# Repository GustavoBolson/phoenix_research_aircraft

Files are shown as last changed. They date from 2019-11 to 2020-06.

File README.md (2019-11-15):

# phoenix_research_aircraft
In an effort to apply my knowledge gained in engineering undergraduate up until this point in a real world, systems engineering based, all-phases design, I will be designing a series of small uncrewed research aircraft to test both aircraft design technics and electronic systems ranging from control to scientific payload that could benefit from having a low-cost, variable acceleration environment. This is supposed to be an easy access venue for future researchers and students who want to replicate my findings or just anyone interested in small planes in general. Fell free to use it on your own project just citing my name and the version that you used.

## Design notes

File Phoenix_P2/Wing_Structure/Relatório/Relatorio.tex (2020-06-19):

\documentclass[a4paper]{article}
\usepackage{fullpage}
\usepackage[utf8]{inputenc}
\usepackage{mathtools}
\usepackage[defaultsans]{comfortaa}
\usepackage[T1]{fontenc}
\usepackage{float}
\usepackage{hyperref}
\usepackage{multicol}
\usepackage{wrapfig}
\usepackage{subcaption}

\title{\Large{\textbf{Relatório Final: Análise de Longarina em Estrutura de Asa para o Avião de Pesquisa Phoenix P2}}}
\author{Gustavo Mancuso Bolson}

\begin{document}

\maketitle

\section{Introdução}

Este relatório é o seguinte da \textit{Proposta de Projeto} após as análises e decisões principais da estrutura das asas do projeto Phoenix P2, o qual \textit{in memoriae} é parte integrante de um esforço multidisciplinar de capacitar e desenvolver conhecimentos que permitam uma maior experiência na área de atuação aeroespacial durante a graduação, através do design, construção, realização de ensaios e voos-teste de um avião não-tripulado de características facilmente modificáveis.

Foi realizada uma série de simulações com dois métodos principais: utilizando uma simulação de barra como o estudado na disciplina com esforços mais precisos e um com diferenças finitas que permite maior controle sobre as características da barra que tem a vantagem de oferecer valores confiáveis de limites de escoamento dos materiais testados mas exige algumas simplificações no cálculo dos esforços. Desta forma podemos ter uma discussão informada sobre qual a escolha mais adequada de material e melhoras para o design proposto inicialmente dentro das escalas fornecidas pelos requisitos, que também são avaliados por conformidade neste relatório.

\section{Determinação de Esforços Aerodinâmicos}

Para determinar os esforços aerodinâmicos atuantes nas asas durante operação que não excede os limites mínimos do envelope de voo esperado, uma série de condições para a carga podem ser modeladas: 

A primeira e mais relevante é que a pressão em toda a superfície da asa é contínua e suavemente variável, o que elimina a validade da análise para uma condição de estol com fluxo altamente turbilhonar e caótico. A decisão é justificada pelas cargas envolvidas serem menores do que as esperadas pela própria natureza deste estado de operação, que envolve uma combinação de ângulo de ataque $\alpha$ elevado combinado com uma baixa velocidade verdadeira do ar. Em conjunto a isso e para evitar prolongações burocráticas acordo com as regras de operação de aeromodelos da Agência Nacional de Aviação Civil (ANAC), a variação de densidade do ar em função à altura máxima de 400 pés AGL \cite{anacdrones} não será considerável o suficiente para afetar a análise, que foi feita utilizando uma temperatura aproximada de 20°C a nível do mar.

A segunda é de que as forças que atuam em cada contato com as nervuras mantém-se constantes com relação às coordenadas locais independentemente de deflexão da longarina. Esta condição é válida pois o perfil de pressão local em um corte a uma distância fixa do engaste da asa é determinado apenas pela forma do aerofólio, seu ângulo de ataque $\alpha$ e o número de Reynolds $R_e$ do fluxo. De acordo com a área planiforme retangular das asas, a razão entre envergadura e comprimento de corda de 10, e a desconsideração dos efeitos aerodinâmicos do engaste de ajuste e corpo da aeronave, podemos utilizar a seguinte equação para aproximar a um coeficiente de distribuição de pressão $\Gamma(y)$ da proporção de distância do engaste x. os valores de $a$ e $k$ são dependentes da razão entre corda e envergadura da asa. Se tomamos o valor de $k=1$ (indicando que os valores de y são em semi-envergadura percorrida normalizada), podemos modelar através de um \textit{fit} \cite{WPIpaper} e então determinar o valor de $a\approx 7.6$.

\vspace{0.5cm}

\begin{equation}
    \Gamma(y) = 1-\left(e^{-a\left(y+k\right)}+e^{a\left(y-k\right)}\right)
\end{equation}

\vspace{0.5cm}

Finalmente, para calcular o perfil de pressões em uma seção de aerofólio, foi utilizado um software de simulação/banco de dados XFOIL \cite{xfoil}. Foram escolhidos 3 estados segundo o envelope de voo mínimo, os quais são apresentados a seguir com suas condições de contorno e os resultados de distribuições de pressão que são condensados em forças pontuais para modelagem dos esforços na longarina. Os estados são escolhidos segundo os diagramas polares do aerofólio escolhido (NACA 23015) nos regimes esperados \cite{aftools}.

\begin{figure}[H]
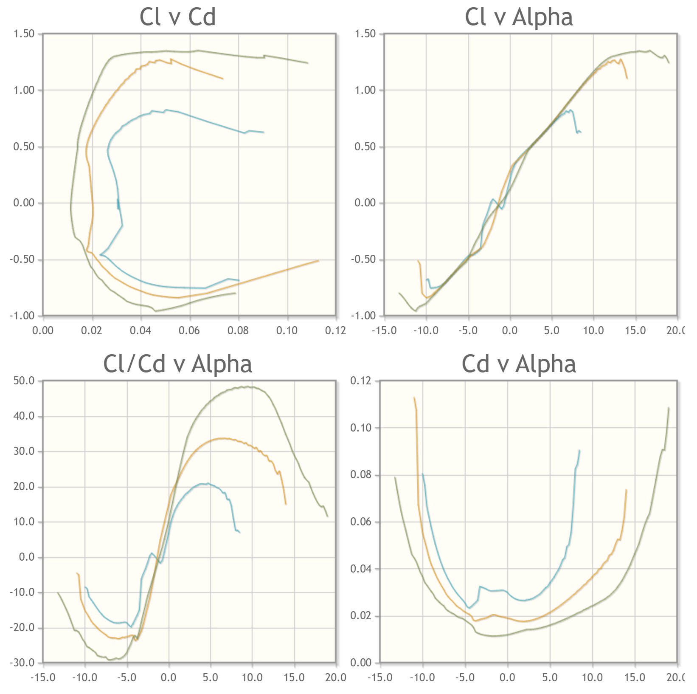
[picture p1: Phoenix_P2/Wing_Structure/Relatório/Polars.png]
    
\end{figure}

A seguir apresentamos 4 estados de operação esperados do aerofólio, incluindo em uma velocidade média esperada para voos iniciais e pré-pousos e outras 3 nas velocidades máximas esperadas variando apenas o ângulo de ataque. Como o terceiro estado (análogo a uma curva coordenada com a maior aceleração centrípeta à maior velocidade esperada) apresenta a maior carga à qual as asas estarão submetidas, esta será a considerada para a análise de esforços. É importante lembrar que qualquer ângulo maior do que 15° a um $R_e=2\times10^5$ resulta em condição de estol, o que reduz a carga na asas.

\begin{figure}[H]
    \begin{subfigure}[b]{0.48\textwidth}
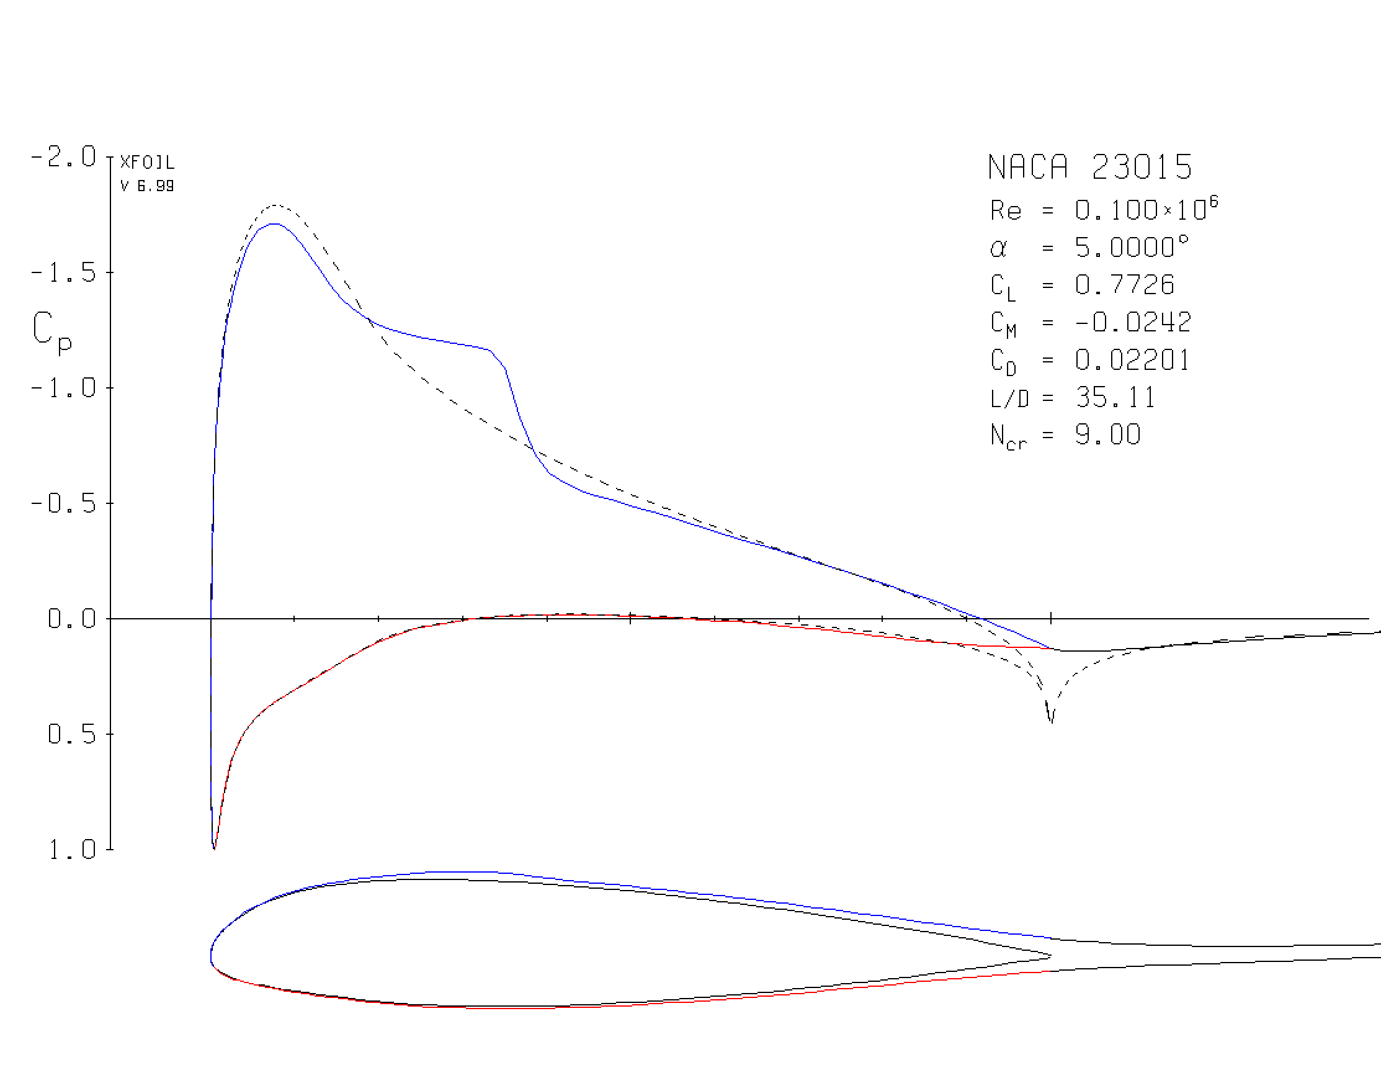
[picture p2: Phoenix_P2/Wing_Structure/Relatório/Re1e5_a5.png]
      
      \caption*{Operação Normal: $\alpha$ = 5° a 8m/s}
    \end{subfigure}
    %
    \begin{subfigure}[b]{0.48\textwidth}
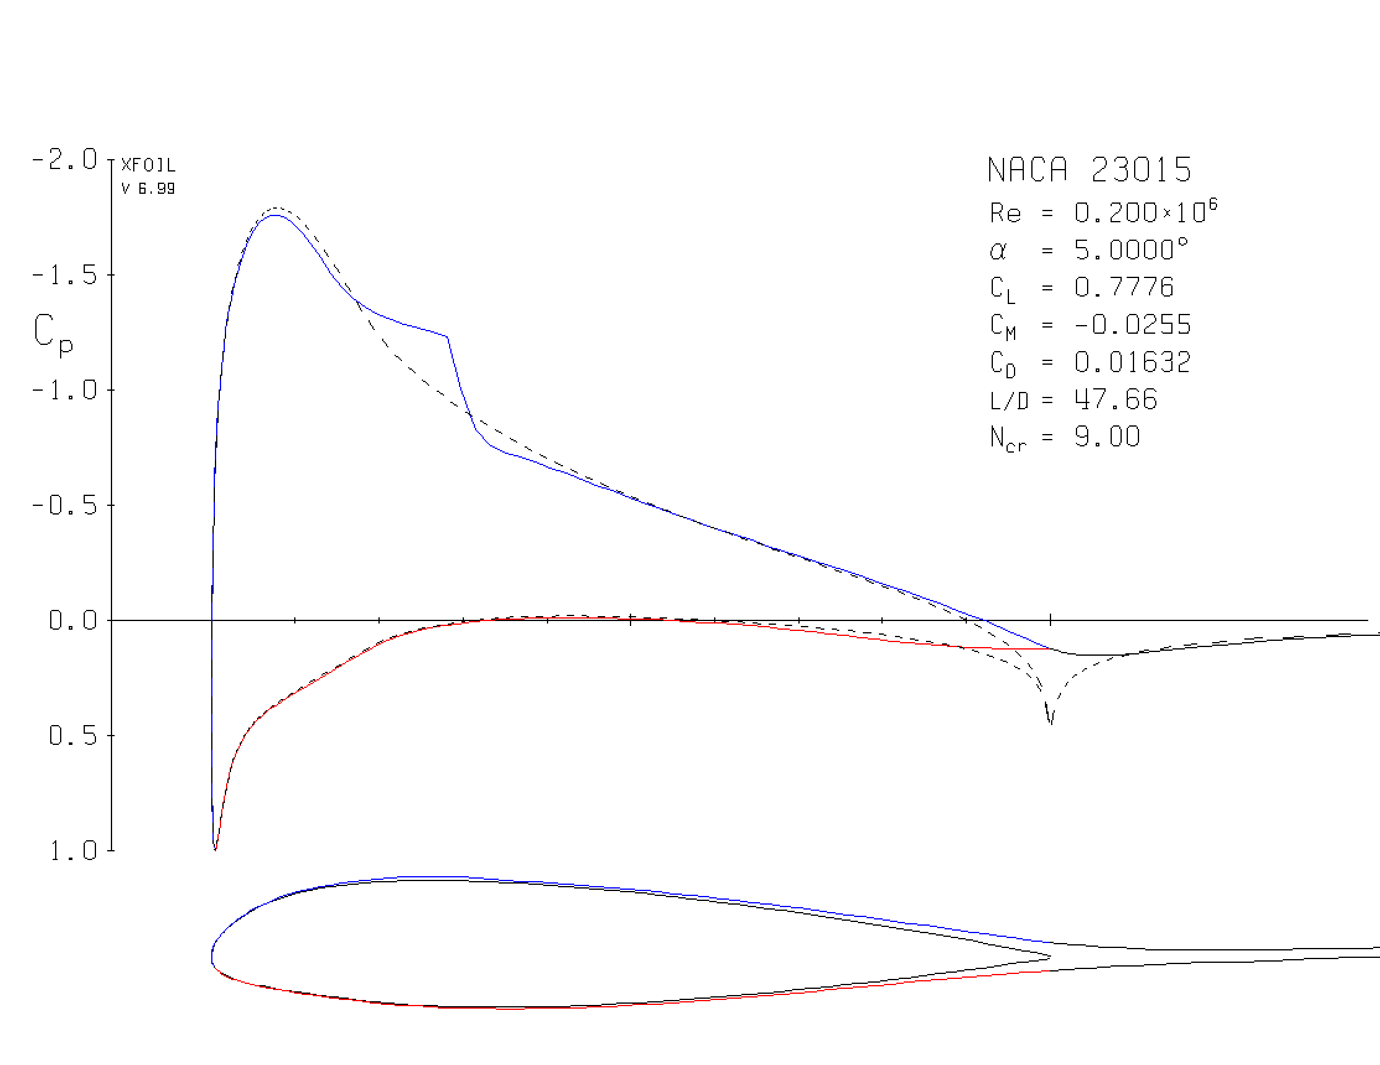
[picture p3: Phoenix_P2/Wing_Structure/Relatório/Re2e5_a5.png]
      
      \caption*{Max. Velocidade: $\alpha$ = 5° a 15m/s}
    \end{subfigure}
\end{figure}

\begin{figure}[H]
    \begin{subfigure}[b]{0.48\textwidth}
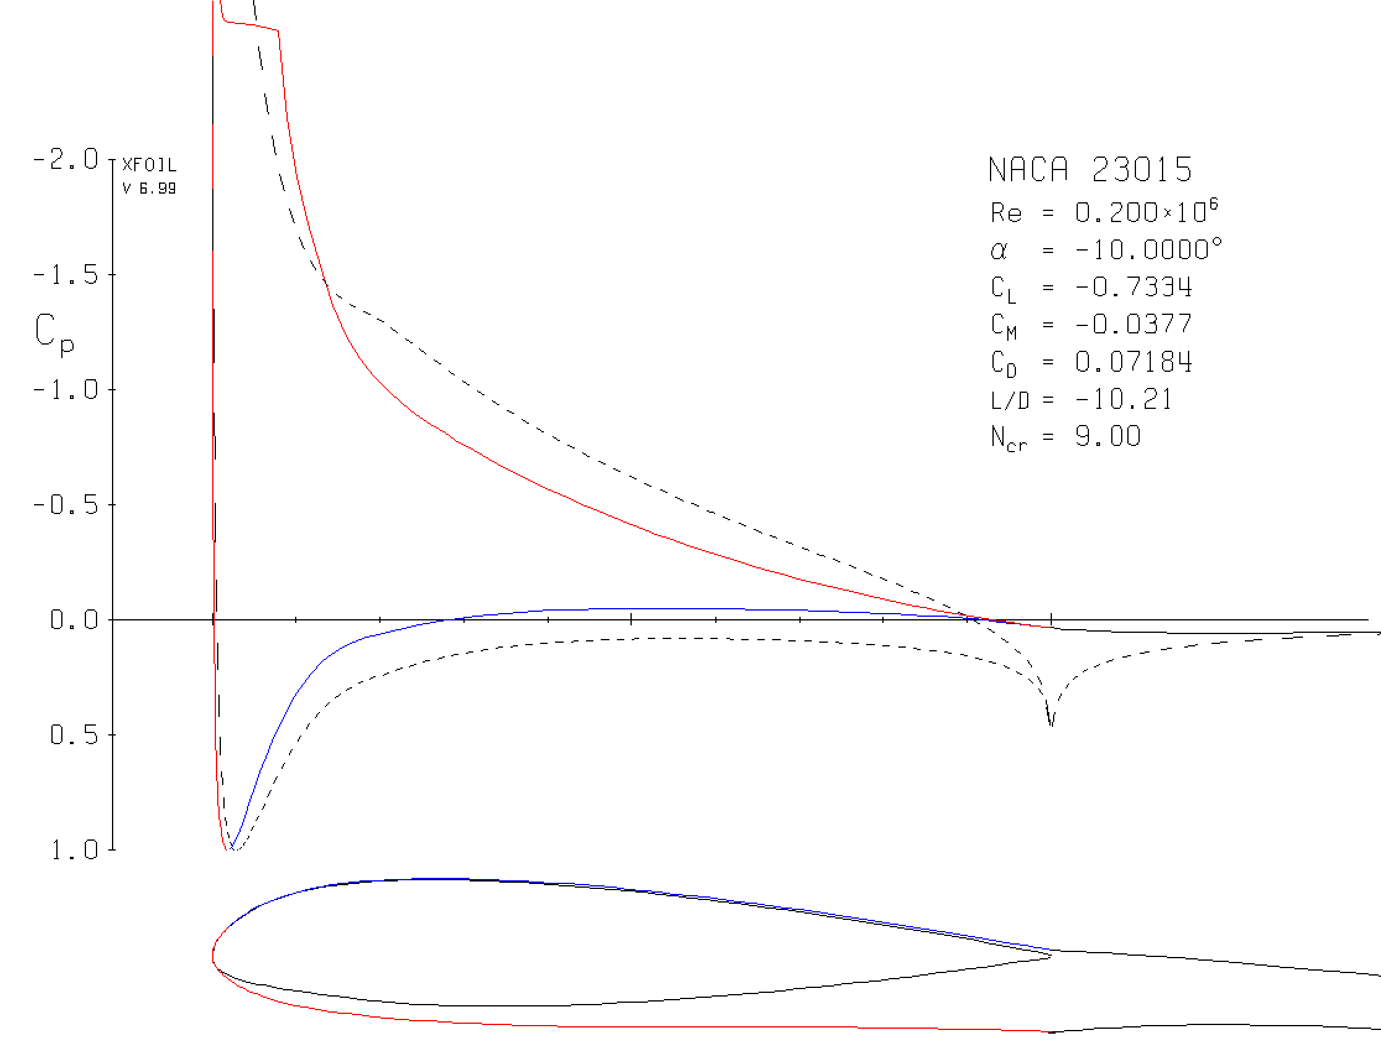
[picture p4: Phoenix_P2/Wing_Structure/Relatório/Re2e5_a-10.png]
      
      \caption*{Max. Velocidade: $\alpha$ = -10° a 15m/s}
    \end{subfigure}
    %
    \begin{subfigure}[b]{0.48\textwidth}
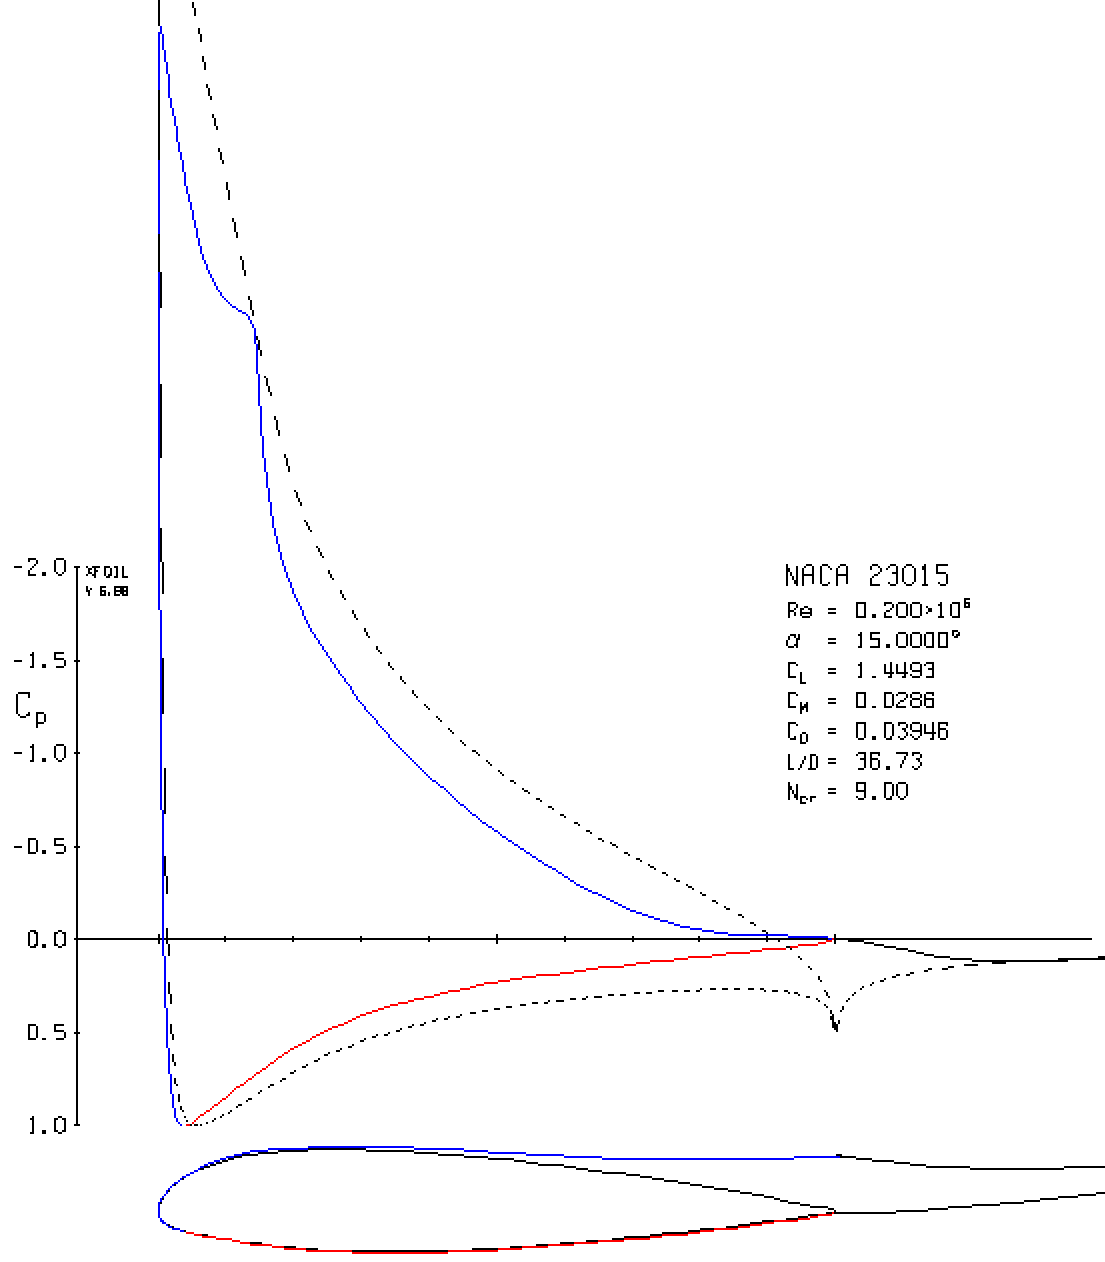
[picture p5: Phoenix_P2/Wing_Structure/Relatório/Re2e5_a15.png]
      
      \caption*{Max. Velocidade: $\alpha$ = 15° a 15m/s}
    \end{subfigure}
\end{figure}

Por fim, podemos tomar os coeficientes adquiridos para calcular quais são as forças de sustentação e arrasto segundo as equações (2) e (3) respectivamente. Os pontos de aplicação da força $L$ e, por consequência, torques envolvidos em cada seção de área é calculada por um \textit{fit} de spline dos diagramas acima, e o perfil é modelado linearmente em coeficiente de $\Gamma(y)$. As equações consideram o centro de coordenadas como sendo a linha de ataque do aerofólio. As medidas são considerando envergadura e corda normalizadas para 1, e são aplicadas para cada nervura. Os termos adicionais são derivados da teoria apresentada por Anderson (2017) \cite{anderson}. Todos as formulas utilizam unidades do sistema internacional.

\vspace{0.5cm}

\begin{minipage}{.47\linewidth}
    \begin{equation}
        L_n = C_L \frac{1}{2} \rho V^2 l \int_{y_{n-1}}^{y_{n+1}} \frac{\Gamma(y)}{2} dy
    \end{equation}
    \begin{equation}
        D_n = C_D \frac{1}{2} \rho V^2 l \int_{y_{n-1}}^{y_{n+1}} \frac{\Gamma(y)}{2} dy + D_0
    \end{equation}
\end{minipage}
\begin{minipage}{.47\linewidth}
    \begin{equation}
        M_x = L (y_L) + C_L \frac{1}{2} \rho V^2 l (1 - \int_{y_{n-1}}^{y_{n+1}} \frac{\Gamma(y)}{2} dy) = 0
    \end{equation}
    \begin{equation}
        M_y = L (x_L - 0.3)
    \end{equation}
    \begin{equation}
        M_z = 0
    \end{equation}
\end{minipage}

\vspace{0.5cm}

\section{Análise de Esforços na Longarina}

Para a execução dos cálculos, foi utilizado a ferramenta de simulação estática do SolidWorks com 10 segmentos como os especificados na \textit{Proposta de Projeto}. Para motivo desta primeira análise, a geometria da seção reta pode ser desconsiderada quando tratamos dos esforços. Em cada junção da barra foi aplicado um par de forças linearmente independentes e um momento torsor, que estão representados na tabela abaixo:

\begin{table}[H]
    \begin{tabular}{llllllllllll}
    y{[}$m${]}   & 0                          & 0.1                         & 0.2                         & 0.3                         & 0.4                         & 0.5                         & 0.6                         & 0.7                         & 0.8                         & 0.9                        & 1                          \\ \cline{2-12} 
    \multicolumn{1}{l|}{$L$} & \multicolumn{1}{l|}{9.804} & \multicolumn{1}{l|}{19.602} & \multicolumn{1}{l|}{19.579} & \multicolumn{1}{l|}{19.524} & \multicolumn{1}{l|}{19.404} & \multicolumn{1}{l|}{19.147} & \multicolumn{1}{l|}{18.598} & \multicolumn{1}{l|}{17.423} & \multicolumn{1}{l|}{14.911} & \multicolumn{1}{l|}{9.540} & \multicolumn{1}{l|}{2.940} \\ \cline{2-12} 
    \multicolumn{1}{l|}{$D$}     & \multicolumn{1}{l|}{1.482} & \multicolumn{1}{l|}{1.481}  & \multicolumn{1}{l|}{1.481}  & \multicolumn{1}{l|}{1.479}  & \multicolumn{1}{l|}{1.476}  & \multicolumn{1}{l|}{1.469}  & \multicolumn{1}{l|}{1.454}  & \multicolumn{1}{l|}{1.422}  & \multicolumn{1}{l|}{1.354}  & \multicolumn{1}{l|}{1.207} & \multicolumn{1}{l|}{1.028} \\ \cline{2-12} 
    \multicolumn{1}{l|}{$M_y$}     & \multicolumn{1}{l|}{0.686} & \multicolumn{1}{l|}{1.372}  & \multicolumn{1}{l|}{1.370}  & \multicolumn{1}{l|}{1.366}  & \multicolumn{1}{l|}{1.358}  & \multicolumn{1}{l|}{1.340}  & \multicolumn{1}{l|}{1.301}  & \multicolumn{1}{l|}{1.219}  & \multicolumn{1}{l|}{1.043}  & \multicolumn{1}{l|}{0.667} & \multicolumn{1}{l|}{0.205} \\ \cline{2-12} 
    \end{tabular}
\end{table}

Com os valores acima podemos então obter os resultados apresentados abaixo para todos os esforços solicitantes na barra. É interessante observar que a discretização de 11 nervuras ao longa da longarina já permite uma aproximação considerável de uma pressão contínua agindo sobre a barra. É importante notar que o programa usa outra convenção de representação da utilizada na disciplina.

\begin{figure}[H]
    \begin{subfigure}[b]{0.48\textwidth}
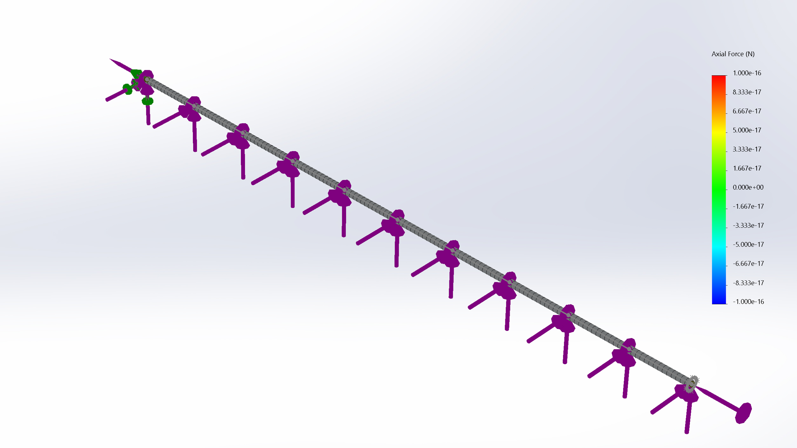
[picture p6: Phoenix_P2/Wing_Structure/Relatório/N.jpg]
      
      \caption*{Força normal $N(y)$}
    \end{subfigure}
    %
    \begin{subfigure}[b]{0.48\textwidth}
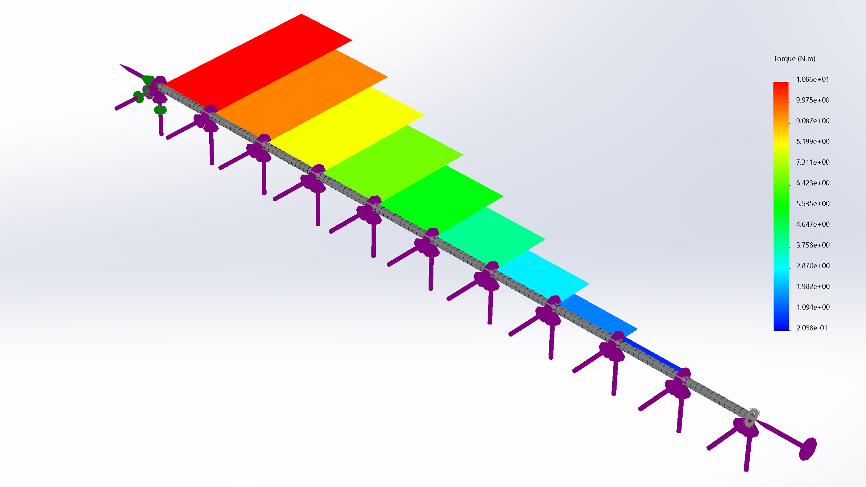
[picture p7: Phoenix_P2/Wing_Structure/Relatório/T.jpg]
      
      \caption*{Momento Torsor $T(y)$}
    \end{subfigure}
\end{figure}

\begin{figure}[H]
    \begin{subfigure}[b]{0.48\textwidth}
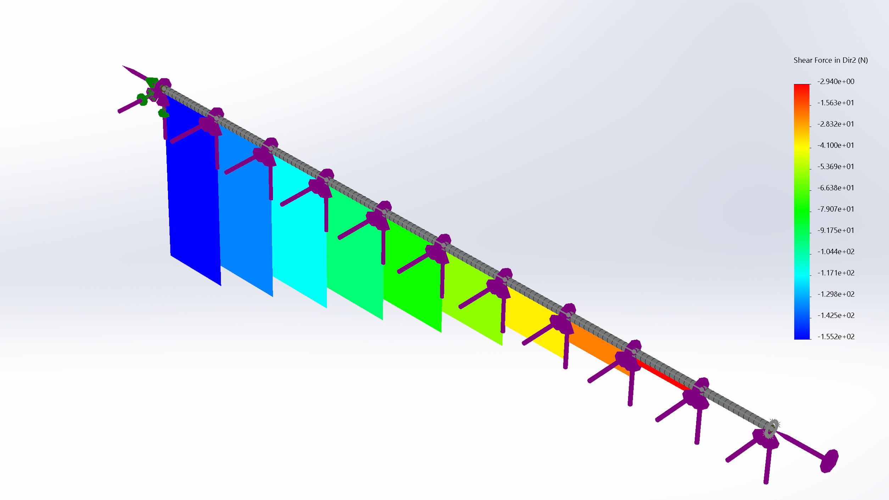
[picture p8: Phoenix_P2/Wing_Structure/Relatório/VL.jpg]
      
      \caption*{Força Cortante de L $V_z(y)$}
    \end{subfigure}
    %
    \begin{subfigure}[b]{0.48\textwidth}
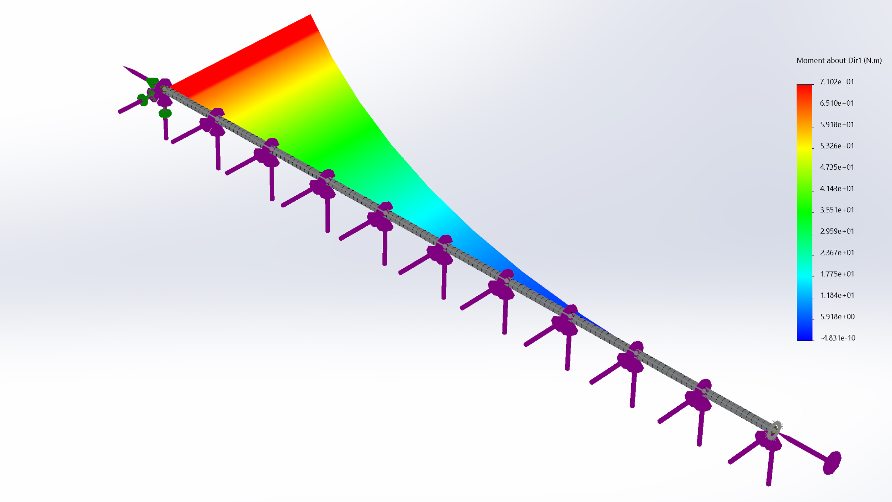
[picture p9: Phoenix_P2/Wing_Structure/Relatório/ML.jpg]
      
      \caption*{Momento de L $M_x(y)$}
    \end{subfigure}
\end{figure}

\begin{figure}[H]
    \begin{subfigure}[b]{0.48\textwidth}
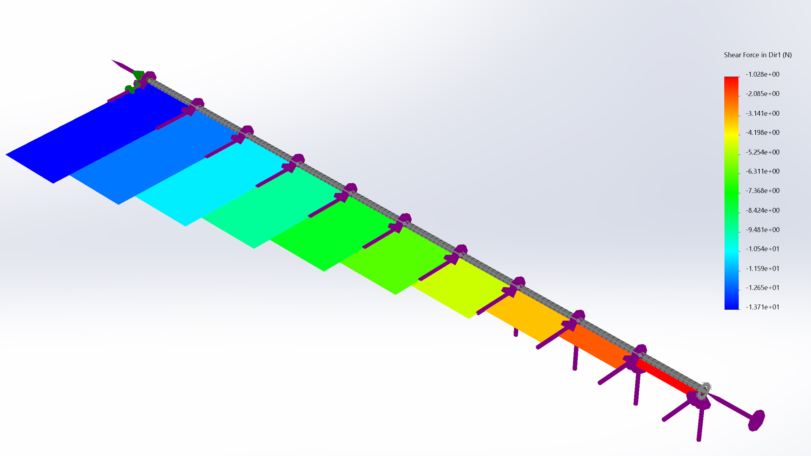
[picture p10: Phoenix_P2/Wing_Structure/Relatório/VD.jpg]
      
      \caption*{Força Cortante de D $V_x(y)$}
    \end{subfigure}
    %
    \begin{subfigure}[b]{0.48\textwidth}
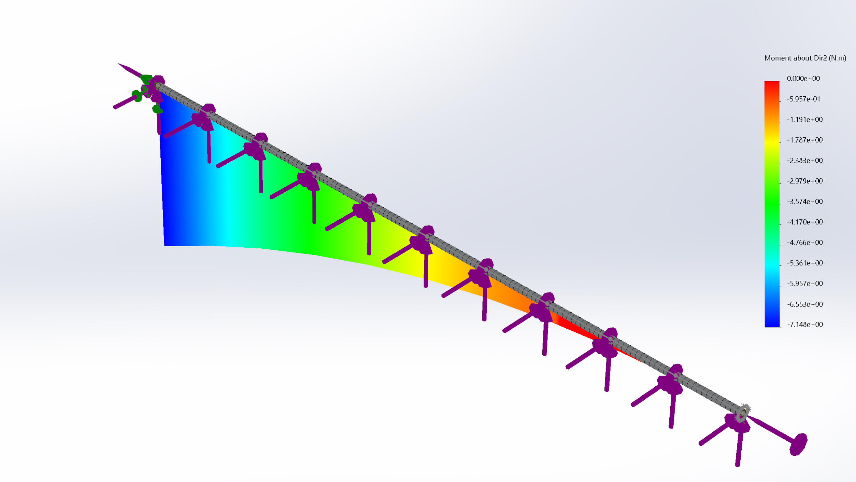
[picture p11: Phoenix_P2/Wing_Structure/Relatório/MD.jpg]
      
      \caption*{Momento de D $M_z(y)$}
    \end{subfigure}
\end{figure}

Conhecendo estas distribuições de força, podemos então analisar o efeito de materiais e seções retas distintas. Para este exemplo acima, a ferramenta disponibiliza apenas um tubo com diâmetro externo de 21.3 mm e 2.3 mm de espessura (padrão ISO), mas podemos transmitir estes resultados para seções também anulares com outras dimensões de diâmetro e espessura que mantenham aproximadamente a proporção entre a área de seção horizontal (a qual tem uma relação aproximadamente linear com as tensões internas para espessuras finas) e o momento de inercia desta seção. Uma das configurações que permite é justamente a apresentada abaixo.

\begin{figure}[H]
    \begin{subfigure}[b]{0.48\textwidth}
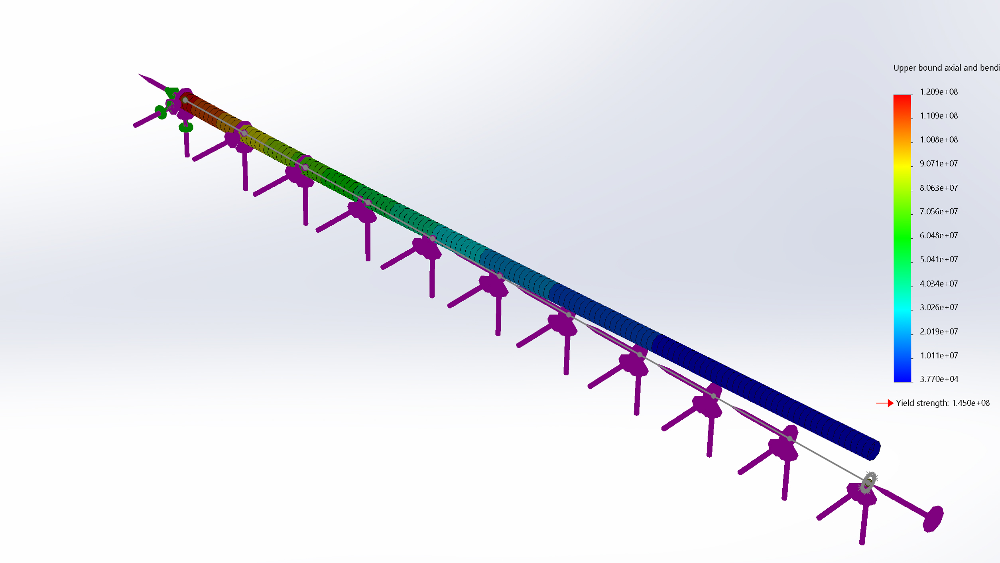
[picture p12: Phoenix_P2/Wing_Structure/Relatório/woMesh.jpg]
      
      \caption*{Barra com configurações limitadas}
    \end{subfigure}
    %
    \begin{subfigure}[b]{0.48\textwidth}
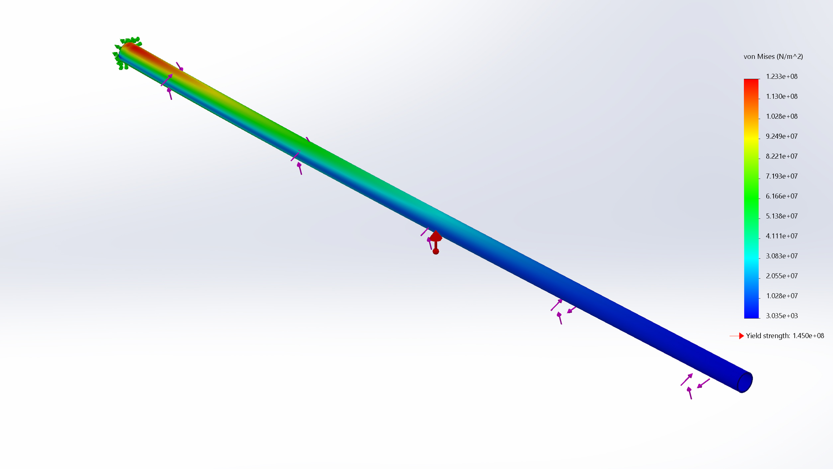
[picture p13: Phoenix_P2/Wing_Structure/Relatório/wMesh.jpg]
      
      \caption*{Barra comercial escolhida}
    \end{subfigure}
\end{figure}

A escolha do material é importante nos aspectos de deformação máxima da barra e tensão máxima de escoamento. Foram testados diversos materiais como PVC rígido, diferentes ligas de alumínio (especialmente da série 6000), e aço AISI 1020. A construção em PVC, além de ter uma deformação muito elevada para pequenas forças, ultrapassava seu limite de escoamento. O aço foi utilizado como referência e seria a escolha caso não fosse encontrada uma liga de alumínio que atendesse as especificações, mas sua densidade resultava em um peso final que exigiria a não-conformação com os requisitos estabelecidos. 

Para o alumínio, a melhor configuração que estava disponível no mercado foi um tubo de $25.4 mm$ ($1''$) com $1.58 mm$ de espessura de Alumínio estrudado 6063-T5, a qual atende a todos os requisitos com uma massa de $0.32 kg$ para a estrutura completa de uma asa. Além disso, considerando que o limite de escoamento desta liga é de $1.45 \times 10^8 N/m^2$, a estrutura nos dá um fator de segurança de aproximadamente $1.17$, o que é perfeito para uma aplicação aeronáutica não-tripulada, que deve ter uma performance elevada e seu custo de perda (especialmente em material e horas-trabalho) não é muito elevado.

\section{Correspondência aos Objetivos do Estudo}

Para entender a validade dos resultados obtidos, comparamos a seguir com os objetivos-pergunta da proposta do estudo aqui apresentado:

\begin{itemize}
    \item Considerando o tubo longitudinal que forma a longarina, o quão espeça deve ser parede do tubo considerando o carregamento esperado?
\end{itemize}

\noindent Com relação à proposta, foi feita a modificação de aumentar o diâmetro externo da longarina, motivado por uma mudança de configuração que permitiu diâmetros de $25.4mm$. Para este novo diâmetro, a espessura fica sendo igual a $1.58mm$ para alumínio 6063-T5 disponível em distribuidores como o seguinte: \url{https://www.aluminioalure.com.br/ye4hdjqia-tubo-redondo-de-aluminio-1-x-116-254cm-x-158mm}

\begin{itemize}
    \item Dados os possíveis materiais a serem utilizados na construção desta estrutura, quais os diâmetros de barras que seriam necessários para cada material?
\end{itemize}

\noindent Esta pergunta provou não ser muito pertinente para a análise dadas as limitações da ferramenta e/ou a não familiaridade com a mesma. É possível dizer que entre os 3 principais materiais considerados, o PVC exige dimensões incompatíveis com o aerofólio, o alumínio permite manter o diâmetro máximo e mesmo assim respeitar os limites de massa, o o aço pode ter um diâmetro ainda menor que o alumínio, mas não obedecia os requisitos de massa.

\begin{itemize}
    \item Em resultado da análise, é possível atingir todos os requisitos de design especificados com esta configuração de estrutura?
\end{itemize}

\noindent Sim. Todos os requisitos especificados na \textit{Proposta de Projeto} foram atingidos com êxito e mantendo uma margem considerável para utilização em estruturas associadas, como as nervuras, superfície aerodinâmica, e mesmo para os requisitos de primeira ordem sobre performance esperada.

\begin{thebibliography}{9}
    \bibitem{anacdrones} 
    Agência Nacional de Aviação Civil,   
    \textit{Orientações para Usuários de drones}.
    \\\url{www.anac.gov.br/assuntos/paginas-tematicas/drones/orientacoes\_para\_usuarios.pdf}

    \bibitem{xfoil} 
    Drela and Youngren,   
    \textit{XFOIL: Subsonic Airfoil Development System}.
    \\\url{https://web.mit.edu/drela/Public/web/xfoil/}

    \bibitem{aftools}    
    \textit{Airfoil Tools}.
    \\\url{http://www.airfoiltools.com/airfoil/details?airfoil=naca23015-il#polars}

    \bibitem{anderson}
    Anderson,
    \textit{Fundamentals of Aerodynamics, 6th ed}
    \\\texttt{ISBN 978-1-259-12991-9}

    \bibitem{WPIpaper}
    Sathaye,
    \textit{Lift Distributions on Low Aspect Ratio Wings at Low Reynolds Numbers},
    \\M.Sc. Thesis, Worcester Polytechnic Institute

\end{thebibliography}

\end{document}

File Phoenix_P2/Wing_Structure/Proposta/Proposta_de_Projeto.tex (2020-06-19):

\documentclass[a4paper]{article}
\usepackage{fullpage}
\usepackage[utf8]{inputenc}
\usepackage{mathtools}
\usepackage[defaultsans]{comfortaa}
\usepackage[T1]{fontenc}
\usepackage{float}

\usepackage{pgfgantt}

\renewcommand{\labelenumii}{\theenumii}
\renewcommand{\theenumii}{\theenumi.\arabic{enumii}.}

%\usepackage[T1]{fontenc}
%\renewcommand*\familydefault{\sfdefault}

%\usepackage{sansmathfonts}
%\usepackage[T1]{fontenc}
%\renewcommand*\familydefault{\sfdefault}

%\usepackage[default,osfigures,scale=0.95]{opensans}
%\usepackage[T1]{fontenc}

\title{\Large{\textbf{Proposta de Projeto: Análise de Longarina em Estrutura de Asa para o Avião de Pesquisa Phoenix P2}}}
\author{Gustavo Mancuso Bolson}%S & & \textit{17 de Abril, 2020}}
%\date{\today}

\begin{document}

\maketitle

\section{Introdução}

O projeto proposto é parte integrante de um esforço multidisciplinar de capacitar e desenvolver conhecimentos que permitam um maior experiência na área de atuação aeroespacial durante a graduação, através do design, construção, realização de ensaios e voos-teste de um avião não-tripulado de características facilmente modificáveis, nomeado a seguir de Projeto Phoenix. Para a segunda iteração do projeto denominada Phoenix P2, tal como especificado na descrição de requisitos abaixo, será construída uma asa com componentes de estrutura interna separados dos componentes aerodinâmicos, sendo que o objetivo deste estudo pode ser dividido em três subobjetivos principais:

\begin{itemize}
    \item Considerando o tubo longitudinal que forma a longarina, o quão espeça deve ser parede do tubo considerando o carregamento esperado;
    \item Dados os possíveis materiais a serem utilizados na construção desta estrutura, quais os diâmetros de barras que seriam necessários para cada material;
    \item Em resultado da análise, é possível atingir todos os requisitos de design especificados com esta configuração de estrutura;
\end{itemize}

Sendo estes 3 objetivos extensamente (porém não exaustivamente) discutidos, o resultado deve ser anexado à \textit{Critical Design Review} da iteração, com data esperada para Q3 de 2020.

\section{Especificações do Design da Asa}

Segundo a seção de interesse da \textit{Preliminary Design Review} para a Phoenix P2, a seguinte cadeia de requisitos deve ser atendida para garantir uma integração no processo de engenharia de sistemas:

\begin{itemize}
    \item[1] A aeronave deve ter uma estrutura capaz de voar.
    \item[1.2] A estrutura deve conter asas com capacidade de gerar sustentação total dentro do envelope de voo.
    \item[1.2.1] A asa deve conter uma estrutura interna responsável por transmitir todos os esforços ao acoplamento de ajuste.
    \item[1.2.2] A asa deve conter um envólucro funcionando de superfície aerodinâmica que transmite seus esforços para as nervuras.
    \item[1.2.3] A asa deve conter nervuras com o perfil do aerofólio para sustentar o envólucro.
    \item[1.2.4] A asa e todas suas estruturas associadas combinadas devem ter massa inferior a 0.80kg.
\end{itemize}

\newpage

Este requisitos analisados juntamente com o conjunto total de requisitos levou a definição preliminar do design a seguir mostrado nas imagens seguintes. Para motivos de visualização da figura 1, as partes consideradas principalmente estruturais estão marcadas de vermelho, enquanto o envólucro é marcado de esmeralda. Para motivos desta análise, consideraremos que as nervuras serão feitas de isopor de alta densidade, e que o envolucro não está engastado em nenhum ponto a não ser em suas bordas. Todas as medidas das duas figuras estão em termos de milímetros.

\begin{figure}[H]
    \centering
    
    \caption{\label{fig:1}}
\end{figure}

A seção transversal da asa, que mantém-se constante durante todo o comprimento, está indicada abaixo com suas dimensões correspondentes. Segundo o design preliminar, foi utilizado um aerofólio NACA 23015 por seu bom desempenho em baixos números de Reynolds e linearidade de coeficientes de sustentação com a variação dos mesmos, simplificado a análise posterior e uma implementação de sistema de controle também posterior. É importante notar que a longarina está posicionada nesta posição da corda do aerofólio para tentar reduzir em regimes de voo diversos a necessidade de transmitir momento torsor, apesar de ainda oferecer resistência ao mesmo dada sua geometria.

\begin{figure}[H]
    \centering
    
    \caption{\label{fig:2}}
\end{figure}

\section{Características da Análise Planejada}

Com o objetivo de simplificar a análise da estrutura, algumas reduções ao modelo são esperadas. A primeira destas é a suposição de que o envólucro aerodinâmico terá massa dispersível com relação ao resto da estrutura, e que este não estará engastado às nervuras, sendo assim desconsiderado para esta análise. O perfil de sustentação assumida não varia conforme a posição longitudinal, sendo assim desconsiderados efeitos de ponta de asa e assumindo assim as curvas de forças bidimensionais do aerofólio, a não ser que a ferramenta de análise possua uma forma simplificada de integração desta característica à análise.

Para análise da longarina, assumiremos que o material escolhido é uniforme e ideal de acordo com tabelas que serão referenciadas ao final. O critério preliminar para a rejeição da configuração simulada será uma diferença de angulo entre as duas extremidades maior do que 20 graus ou a ruptura do material em qualquer dos pontos da longarina.

Os esforços exercidos sobre a superfície aerodinâmica serão determinados de acordo com o cronograma e disponibilidade de ferramentas ou simplificações de cargas em função do envelope de voo.

\section{Cronograma}

O seguinte cronograma apresenta atividades a serem realizadas em nível de abstração relativamente elevado, porém incluem todas as tarefas necessárias para a realização completa de todas as atividades ligadas à análise aqui apresentada. Os itens abaixo indicam períodos como sendo semanas. Nestes períodos, estão reservados para tarefas exclusivas ao projeto Phoenix P2 8 horas por período, às quais podem sofrer variações que não ultrapassem o macro-limite semanal.

\begin{enumerate}
    \item Para a primeira semana, as tarefas são pesquisa adicional sobre estruturas de asa, decisão do software de simulação e cálculo a ser utilizado, fazer ajustes finais na concepção da análise associadas a confirmação pelo professor, determinação de esforços externos e adaptação dos desenhos para o software escolhido;
    \item Na segunda semana, as primeiras simulações necessárias serão executadas e seus resultados serão analisados, as primeiras imagens para descrição dos esforços serão criados;
    \item Na terceira semana, simulações e análises finais, Preparação do documento escrito para ser entregue associado à apresentação, entrega preliminar do documento para checagem do professor.
    \item Por fim, na quarta semana, finalização do documento escrito e distribuição prévia à apresentação, preparação e finalização dos slides, apresentação final e \textit{debriefing}.
\end{enumerate}

Qualquer desvio que se estender além do macro-limite semanal exigirá uma reorganização do cronograma, o que será informado ao professor para garantir a entrega dentro da qualidade esperada e prazo final definido.

\begin{ganttchart}{1}{24}

%\gantttitle{Cronograma Planejado}{24} \\
\gantttitlelist{"Week 1", "Week 2", "Week 3", "Week 4"}{6} \\
\ganttgroup{Group 1}{1}{24} \\
\ganttbar{Pesquisa}{1}{2} \\
\ganttlinkedbar{Task 2}{3}{7} \ganttnewline
\ganttmilestone{Milestone}{7} \ganttnewline
\ganttbar{Final Task}{8}{24}
\ganttlink{elem2}{elem3}
\ganttlink{elem3}{elem4}
\end{ganttchart}

\end{document}

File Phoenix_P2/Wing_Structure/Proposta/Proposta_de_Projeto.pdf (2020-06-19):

## Proposta de Projeto: Análise de Longarina em Estrutura de Asa para o Avião de Pesquisa Phoenix P2

Gustavo Mancuso Bolson

April 23, 2020

## 1 Introdução

O projeto proposto é parte integrante de um esforço multidisciplinar de capacitar e desenvolver conhecimentos que permitam um maior experiência na área de atuação aeroespacial durante a graduação, através do design, construção, realização de ensaios e voos-teste de um avião não-tripulado de características facilmente modificáveis, nomeado a seguir de Projeto Phoenix. Para a segunda iteração do projeto denominada Phoenix P2, tal como especificado na descrição de requisitos abaixo, será construída uma asa com componentes de estrutura interna separados dos componentes aerodinâmicos, sendo que o objetivo deste estudo pode ser dividido em três subobjetivos principais:

- Considerando o tubo longitudinal que forma a longarina, o quão espeça deve ser parede do tubo considerando o carregamento esperado;
- Dados os possíveis materiais a serem utilizados na construção desta estrutura, quais os diâmetros de barras que seriam necessários para cada material;
- Em resultado da análise, é possível atingir todos os requisitos de design especificados com esta configuração de estrutura;

Sendo estes 3 objetivos extensamente (porém não exaustivamente) discutidos, o resultado deve ser anexado à Critical Design Review da iteração, com data esperada para Q3 de 2020.

## 2 Especificações do Design da Asa

Segundo a seção de interesse da Preliminary Design Review para a Phoenix P2, a seguinte cadeia de requisitos deve ser atendida para garantir uma integração no processo de engenharia de sistemas:

1 A aeronave deve ter uma estrutura capaz de voar.

1.2 A estrutura deve conter asas com capacidade de gerar sustentação total dentro do envelope de voo.

1.2.1 A asa deve conter uma estrutura interna responsável por transmitir todos os esforços ao acoplamento de ajuste.

1.2.2 A asa deve conter um envólucro funcionando de superfície aerodinâmica que transmite seus esforços para as nervuras.

1.2.3 A asa deve conter nervuras com o perfil do aerofólio para sustentar o envólucro.

1.2.4 A asa e todas suas estruturas associadas combinadas devem ter massa inferior a 0.80kg.

1

Este requisitos analisados juntamente com o conjunto total de requisitos levou a definição preliminar do design a seguir mostrado nas imagens seguintes. Para motivos de visualização da figura 1, as partes consideradas principalmente estruturais estão marcadas de vermelho, enquanto o envólucro é marcado de esmeralda. Para motivos desta análise, consideraremos que as nervuras serão feitas de isopor de alta densidade, e que o envolucro não está engastado em nenhum ponto a não ser em suas bordas. Todas as medidas das duas figuras estão em termos de milímetros.

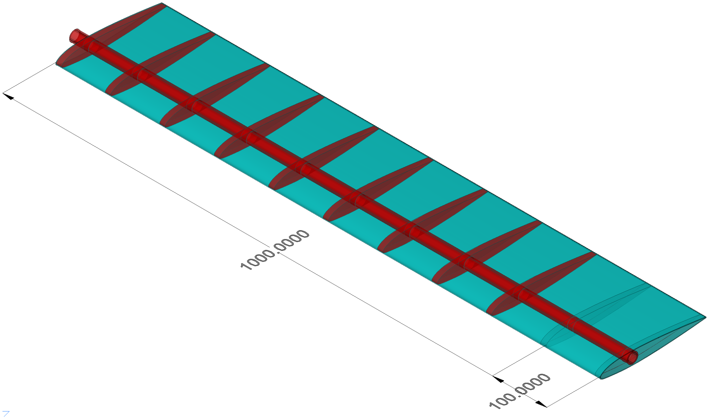
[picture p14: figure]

Figure 1:

A seção transversal da asa, que mantém-se constante durante todo o comprimento, está indicada abaixo com suas dimensões correspondentes. Segundo o design preliminar, foi utilizado um aerofólio NACA 23015 por seu bom desempenho em baixos números de Reynolds e linearidade de coeficientes de sustentação com a variação dos mesmos, simplificado a análise posterior e uma implementação de sistema de controle também posterior. É importante notar que a longarina está posicionada nesta posição da corda do aerofólio para tentar reduzir em regimes de voo diversos a necessidade de transmitir momento torsor, apesar de ainda oferecer resistência ao mesmo dada sua geometria.

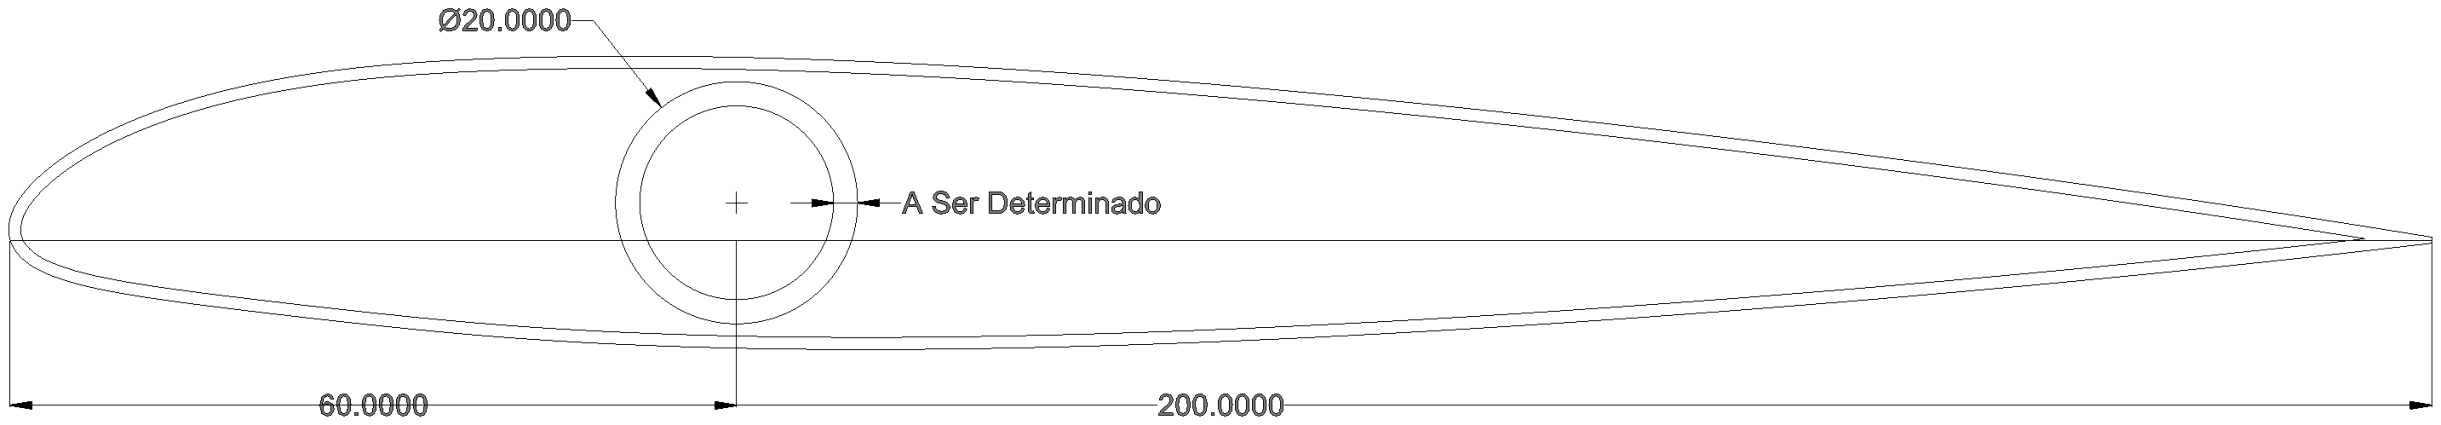
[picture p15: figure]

Figure 2:

2

## 3 Características da Análise Planejada

Com o objetivo de simplificar a análise da estrutura, algumas reduções ao modelo são esperadas. A primeira destas é a suposição de que o envólucro aerodinâmico terá massa dispersível com relação ao resto da estrutura, e que este não estará engastado às nervuras, sendo assim desconsiderado para esta análise. O perfil de sustentação assumida não varia conforme a posição longitudinal, sendo assim desconsiderados efeitos de ponta de asa e assumindo assim as curvas de forças bidimensionais do aerofólio, a não ser que a ferramenta de análise possua uma forma simplificada de integração desta característica à análise. Para análise da longarina, assumiremos que o material escolhido é uniforme e ideal de acordo com tabelas que serão referenciadas ao final. O critério preliminar para a rejeição da configuração simulada será uma diferença de angulo entre as duas extremidades maior do que 20 graus ou a ruptura do material em qualquer dos pontos da longarina.
Os esforços exercidos sobre a superfície aerodinâmica serão determinados de acordo com o cronograma e disponibilidade de ferramentas ou simplificações de cargas em função do envelope de voo.

## 4 Cronograma

O seguinte cronograma apresenta atividades a serem realizadas em nível de abstração relativamente elevado, porém incluem todas as tarefas necessárias para a realização completa de todas as atividades ligadas à análise aqui apresentada. Os itens abaixo indicam períodos como sendo semanas. Nestes períodos, estão reservados para tarefas exclusivas ao projeto Phoenix P2 8 horas por período, às quais podem sofrer variações que não ultrapassem o macro-limite semanal.

1. Para a primeira semana, as tarefas são pesquisa adicional sobre estruturas de asa, decisão do software de simulação e cálculo a ser utilizado, fazer ajustes finais na concepção da análise associadas a confirmação pelo professor, determinação de esforços externos e adaptação dos desenhos para o software escolhido;
2. Na segunda semana, as primeiras simulações necessárias serão executadas e seus resultados serão analisados, as primeiras imagens para descrição dos esforços serão criados;
3. Na terceira semana, simulações e análises finais, Preparação do documento escrito para ser entregue associado à apresentação, entrega preliminar do documento para checagem do professor.
4. Por fim, na quarta semana, finalização do documento escrito e distribuição prévia à apresentação, preparação e finalização dos slides, apresentação final e debriefing.

Qualquer desvio que se estender além do macro-limite semanal exigirá uma reorganização do cronograma, o que será informado ao professor para garantir a entrega dentro da qualidade esperada e prazo

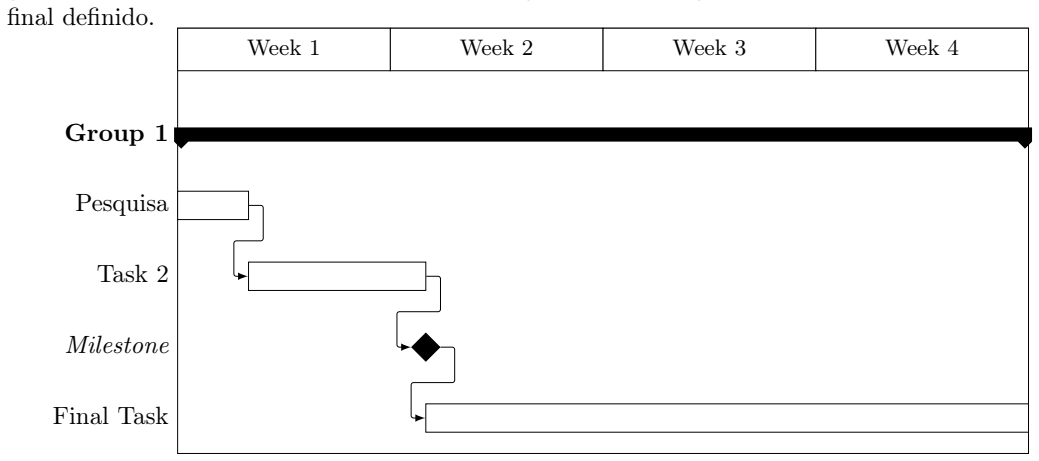
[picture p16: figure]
final definido.; Week 1; Week 2; Week 3; Week 4; Group 1; Pesquisa; Task 2; Milestone; Final Task

3

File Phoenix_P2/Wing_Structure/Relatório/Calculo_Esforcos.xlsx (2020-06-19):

Lift Coefficient | Start y | End y | Pressure Lift in section | Ideal Lift | Zero-lift Drag | Drag Coefficient | Start y | End y | Pressure Drag in section | Total Drag | Torque Moment
-1.4493 | 0 | 0.1 | 9.804586564 | 196.307685 | 0.94815 | -0.03946 | 0 | 0.1 | 0.5338977242 | 1.482047724 | 0.6863210595
-1.4493 | 0 | 0.2 | 19.60263035 |  |  | -0.03946 | 0 | 0.2 | 0.5337195844 | 1.481869584 | 1.372184125
-1.4493 | 0.1 | 0.3 | 19.57903747 |  |  | -0.03946 | 0.1 | 0.3 | 0.5330772224 | 1.481227222 | 1.370532623
-1.4493 | 0.2 | 0.4 | 19.52409855 |  |  | -0.03946 | 0.2 | 0.4 | 0.5315814039 | 1.479731404 | 1.366686898
-1.4493 | 0.3 | 0.5 | 19.40452375 |  |  | -0.03946 | 0.3 | 0.5 | 0.5283257485 | 1.476475748 | 1.358316663
-1.4493 | 0.4 | 0.6 | 19.14785762 |  |  | -0.03946 | 0.4 | 0.6 | 0.5213375157 | 1.469487516 | 1.340350033
-1.4493 | 0.5 | 0.7 | 18.59857518 |  |  | -0.03946 | 0.5 | 0.7 | 0.5063822373 | 1.454532237 | 1.301900263
-1.4493 | 0.6 | 0.8 | 17.42384279 |  |  | -0.03946 | 0.6 | 0.8 | 0.4743978724 | 1.422547872 | 1.219668995
-1.4493 | 0.7 | 0.9 | 14.91183999 |  |  | -0.03946 | 0.7 | 0.9 | 0.4060037301 | 1.35415373 | 1.043828799
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

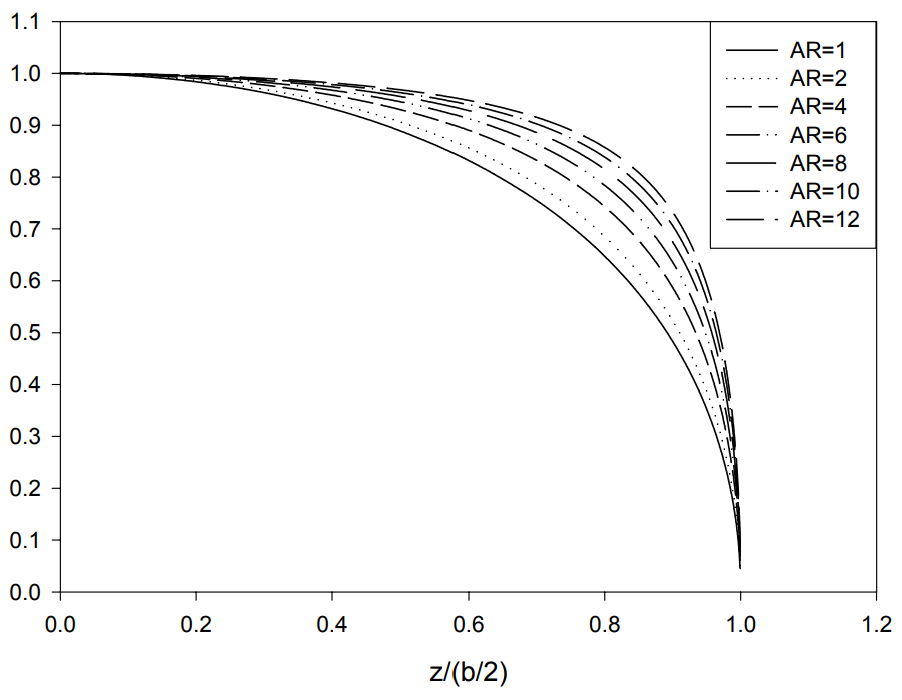
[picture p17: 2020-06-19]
Phoenix_P2/Wing_Structure/Relatório/spanlift.png

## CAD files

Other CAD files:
Phoenix_P2/3D Main.dwg
